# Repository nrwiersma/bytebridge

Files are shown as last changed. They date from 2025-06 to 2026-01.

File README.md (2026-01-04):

<picture>
  <source media="(prefers-color-scheme: dark)" srcset="http://svg.wiersma.co.za/github/project.v2?title=bytebridge&tag=usb%20to%20uart&mode=dark">
  <source media="(prefers-color-scheme: light)" srcset="http://svg.wiersma.co.za/github/project.v2?title=bytebridge&tag=usb%20to%20uart">
  bytebridge&tag=usb%20to%20uart"
</picture>

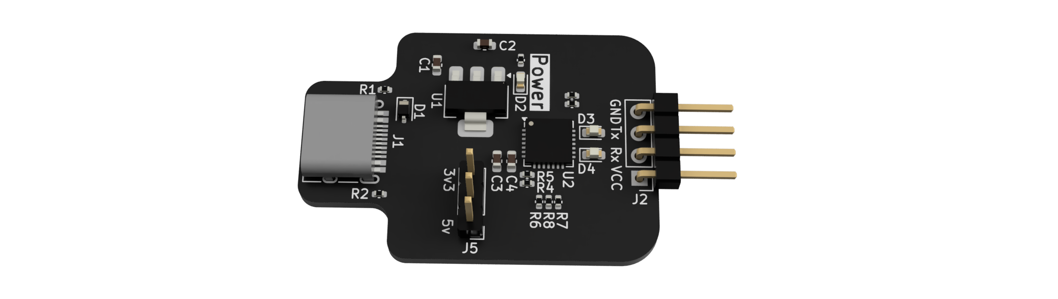
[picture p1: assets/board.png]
board image





`ByteBridge` a USB to UART breakout board with more power.

Features:

* CP2102 bridge
* AMS1117 capable of delivering 1A

## Why

In 2025, dealing with Micro/Mini-USB is a pain. Additionally, most flash boards do not deliver
enough current to power a stock ESP32, making to process more difficult than it needs to be.

## Changelog

#### v0.1.0

* Initial schematic and board

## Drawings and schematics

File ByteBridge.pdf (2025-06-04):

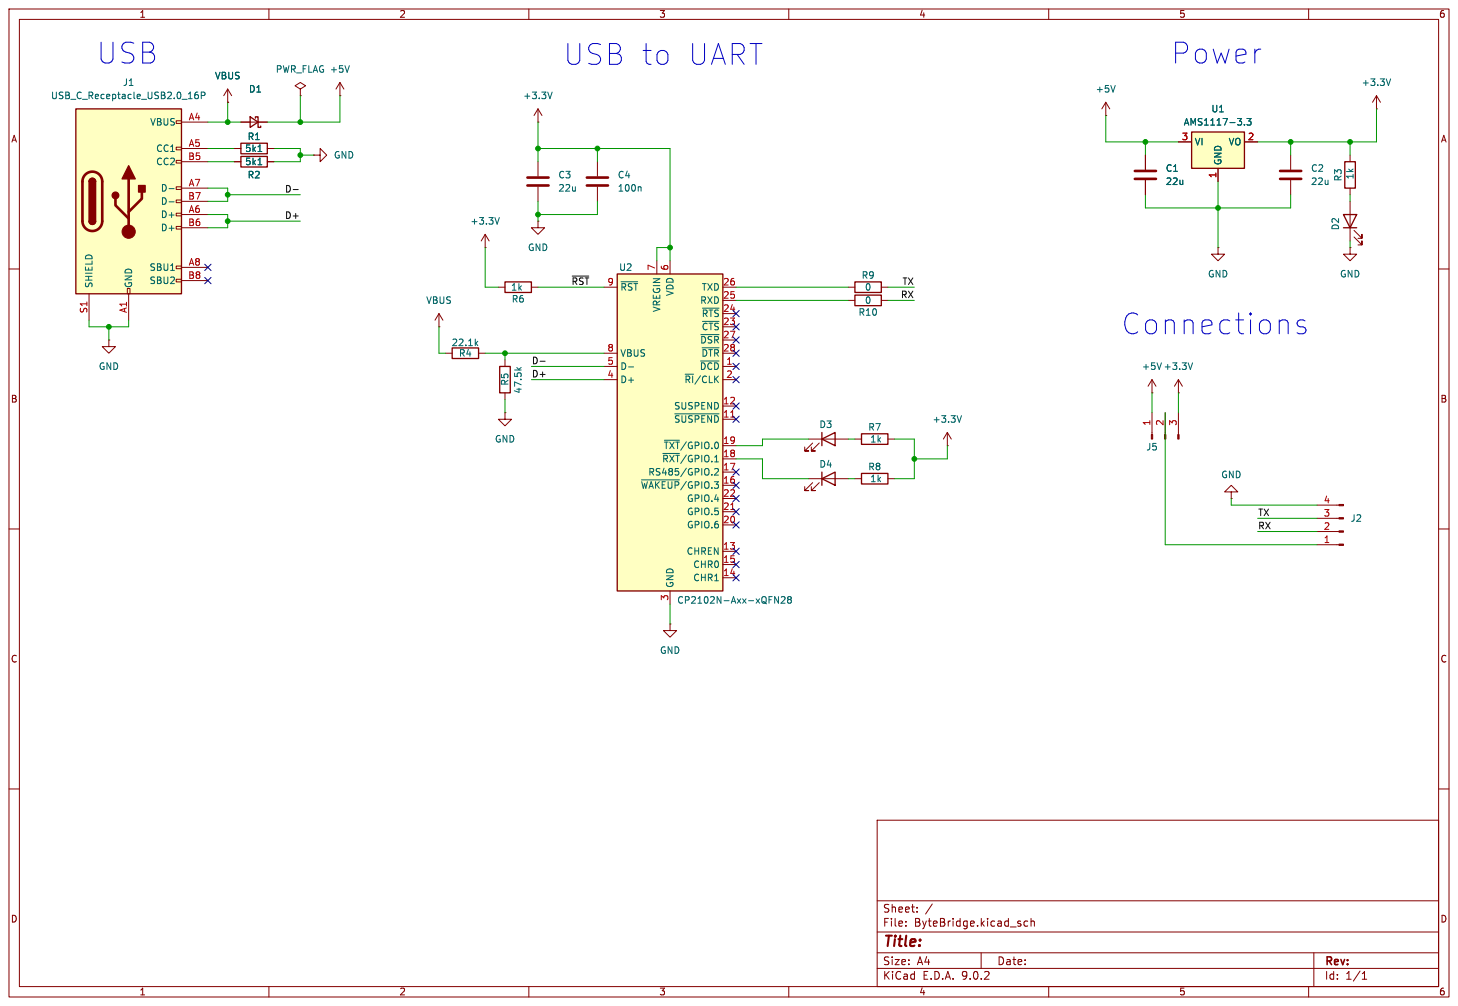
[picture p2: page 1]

3 TXD 26 RXD 25 ~{RTS} 24 ~{CTS} 23 ~{DSR} 27 ~{DTR} 28 ~{DCD}1 ~{RI}/CLK2 SUSPEND 12 ~{SUSPEND}11 ~{TXT}/GPIO.019 ~{RXT}/GPIO.118 RS485/GPIO.2 17 ~{WAKEUP}/GPIO.316 GPIO.4 22 GPIO.5 21 GPIO.6 20 CHREN 13 CHR0 15 CHR1 14 U2 CP2102N-Axx-xQFN28

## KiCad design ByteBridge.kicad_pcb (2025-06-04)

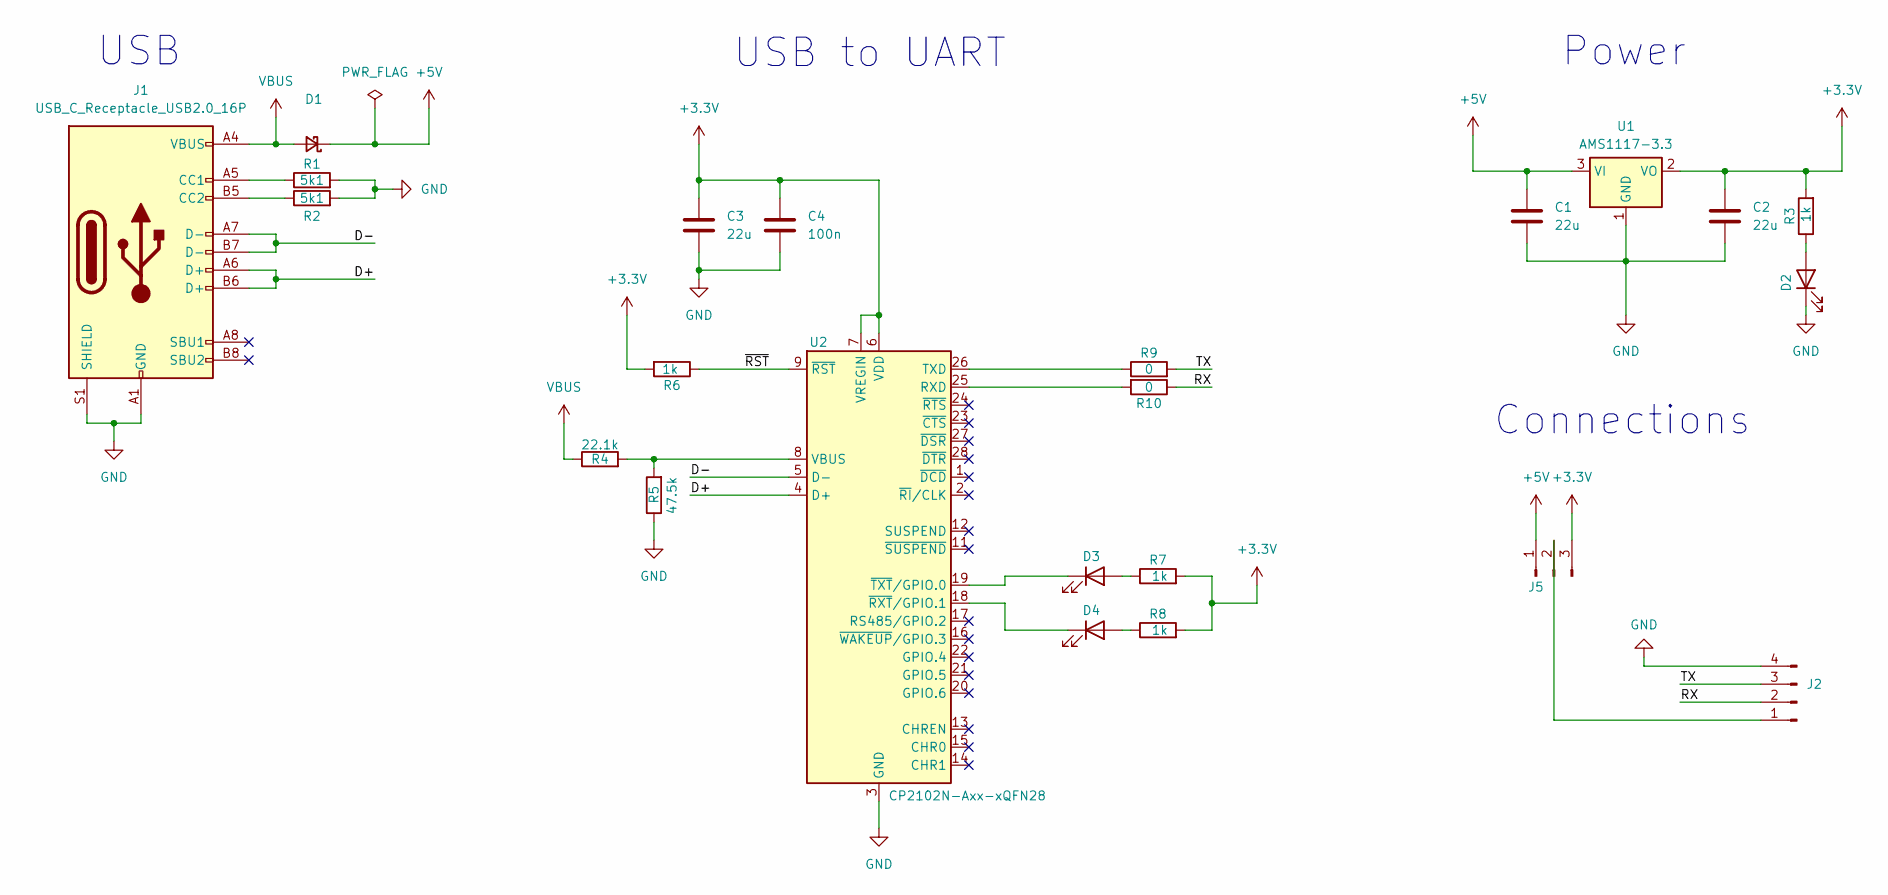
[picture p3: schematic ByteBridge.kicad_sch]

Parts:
C1, C2, C3: 22u; C_0603_1608Metric; MPN CL10A226MQ8NRNC; JLCPCB Part # C59461
C4: 100n; C_0603_1608Metric; MPN CL10B104KB8NNNC; JLCPCB Part # C1591
D1: D_Schottky_Small; D_SOD-323; MPN BAT760-7; JLCPCB Part # C124187
D2: LED; LED_0603_1608Metric; MPN LTST-C191KRKT; JLCPCB Part # C125099
D3, D4: LED; LED_0603_1608Metric; MPN LTST-C191GKT; JLCPCB Part # C99289
J1: USB_C_Receptacle_USB2.0_16P; USB_C_Receptacle_HRO_TYPE-C-31-M-12; MPN TYPE-C-31-M-12; JLCPCB Part # C165948
J2: Conn_01x04_Pin; PinHeader_1x04_P2.54mm_Vertical; MPN PZ254R-11-04P; JLCPCB Part # C492412
J5: Conn_01x03_Pin; PinHeader_1x03_P2.54mm_Vertical; MPN PZ254V-11-03P; JLCPCB Part # C2937625
R1, R2: 5k1; R_0402_1005Metric; MPN RC0402FR-075K1L; JLCPCB Part # C105872
R3, R6, R7, R8: 1k; R_0402_1005Metric; MPN RK73H1ETTP1001F; JLCPCB Part # C131360
R4: 22.1k; R_0402_1005Metric; MPN RC0402FR-0722K1L; JLCPCB Part # C163478
R5: 47.5k; R_0402_1005Metric; MPN RC0402FR-0747K5L; JLCPCB Part # C137974
R9, R10: 0; R_0402_1005Metric; MPN RC0402JR-070RL; JLCPCB Part # C60485
U1: AMS1117-3.3; SOT-223-3_TabPin2; MPN AMS1117-3.3; JLCPCB Part # C347222
U2: CP2102N-Axx-xQFN28; QFN-28-1EP_5x5mm_P0.5mm_EP3.35x3.35mm; MPN CP2102N-A02-GQFN28R; JLCPCB Part # C964632

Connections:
+3.3V: C2.1, C3.1, C4.1, J5.3, R3.2, R6.2, R7.2, R8.2, U1.2 (VO), U2.6 (VDD), U2.7 (VREGIN)
+5V: C1.1, D1.1 (K), J5.1, U1.3 (VI)
/D+: J1.A6 (D+), J1.B6 (D+), U2.4 (D+)
/D-: J1.A7 (D-), J1.B7 (D-), U2.5 (D-)
/RX: J2.2, R10.1
/TX: J2.3, R9.2
/~RST: R6.1, U2.9 (~RST)
GND: C1.2, C2.2, C3.2, C4.2, D2.1 (K), J1.A1 (GND), J1.A12 (GND), J1.B1 (GND), J1.B12 (GND), J1.S1 (SHIELD), J2.4, R1.2, R2.2, R5.1, U1.1 (GND), U2.3 (GND), U2.29 (GND)
unnamed: D2.2 (A), R3.1
unnamed: D3.2 (A), R7.1
unnamed: D3.1 (K), U2.19 (~TXT/GPIO.0)
unnamed: D4.2 (A), R8.1
unnamed: D4.1 (K), U2.18 (~RXT/GPIO.1)
unnamed: J1.A5 (CC1), R1.1
unnamed: J1.B5 (CC2), R2.1
unnamed: J2.1, J5.2
unnamed: R10.2, U2.25 (RXD)
unnamed: R9.1, U2.26 (TXD)
unnamed: R4.2, R5.2, U2.8 (VBUS)
VBUS: D1.2 (A), J1.A4 (VBUS), J1.A9 (VBUS), J1.B4 (VBUS), J1.B9 (VBUS), R4.1

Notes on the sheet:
Connections
USB
Power
USB to UART

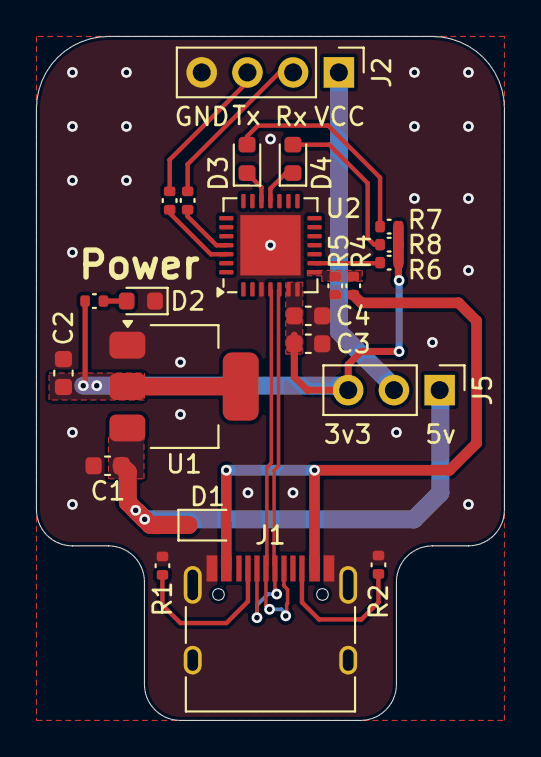
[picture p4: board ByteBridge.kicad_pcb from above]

Board: 2 copper layers, 26.0 x 38.0 mm, 23 parts (0 on the bottom side), 20 nets.

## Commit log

2025-06-04 feat: initial board (#1)
    [ByteBridge.kicad_pcb, ByteBridge.kicad_sch]
2026-01-04 chore: update board image

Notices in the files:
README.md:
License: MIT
